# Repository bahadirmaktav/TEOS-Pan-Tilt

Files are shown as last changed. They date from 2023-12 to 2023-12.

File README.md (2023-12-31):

# Teos Pan Tilt
Teos Pan Tilt is a robotic camera project that can pan horizontally and tilt vertically by controlling it via a user interface.</br>
Source codes and design files related to the software, firmware and mechanical design of the project are located in Teos-Pan-Tilt repository.

## Table of Contents
- [Getting Started](#getting-started)
    - [Firmware](#firmware)
    - [Software](#software)
    - [Mechanics](#mechanics)
- [How To Use](#how-to-use)
- [Demo](#demo)
- [Roadmap](#roadmap)
- [License](#license)

## Getting Started
The project basically consists of three folders.</br>
1. The folder named **firmware** contains the source codes running in the camera module used in the project.
2. The folder named **software** contains the source codes of the user interface.
3. The folder named **mechanics** contains files related to the mechanical design of the project.

### Firmware
The **firmware** runs on the ESP32-CAM module. The v5.1 version of the Espressif IoT Development Framework (IDF) was used in the development of the firmware.</br>
Basically, the functions of the firmware are as follows.</br>
1. Connects to the WiFi network specified in the configuration.
2. Starts a WebSocket server.
3. Rotates the pan and tilt cameras according to the commands coming from the user interface via websocket.
4. Sends camera images to the user interface via websocket according to the camera start/stop command coming from the user interface.

### Software
The **software** is a user interface developed with python (tkinter library) that can run in Windows or Linux environments.</br>
Basically, the functions of the software are as follows.</br>
1. Sends command messages to the websocket server according to the input from the user.
2. Displays the visual data coming from the server in video format on the user interface when the camera is started.

### Mechanics
The **mechanics** contain 3D design files in 3mf format developed with Fusion 360.</br>
The mechanical system was designed so that the module with the camera can move in two axes with servo motors.

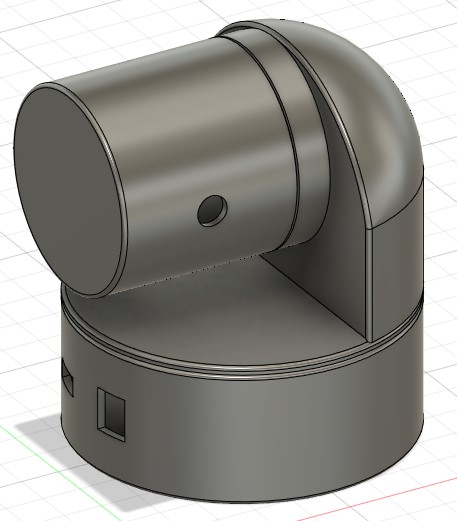
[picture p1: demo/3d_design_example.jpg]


## How To Use
Teos Pan Tilt is controlled from the user interface that appears on the screen by running the source code in the software folder.</br>
An example user interface image for the final version of the project is shared below.</br>

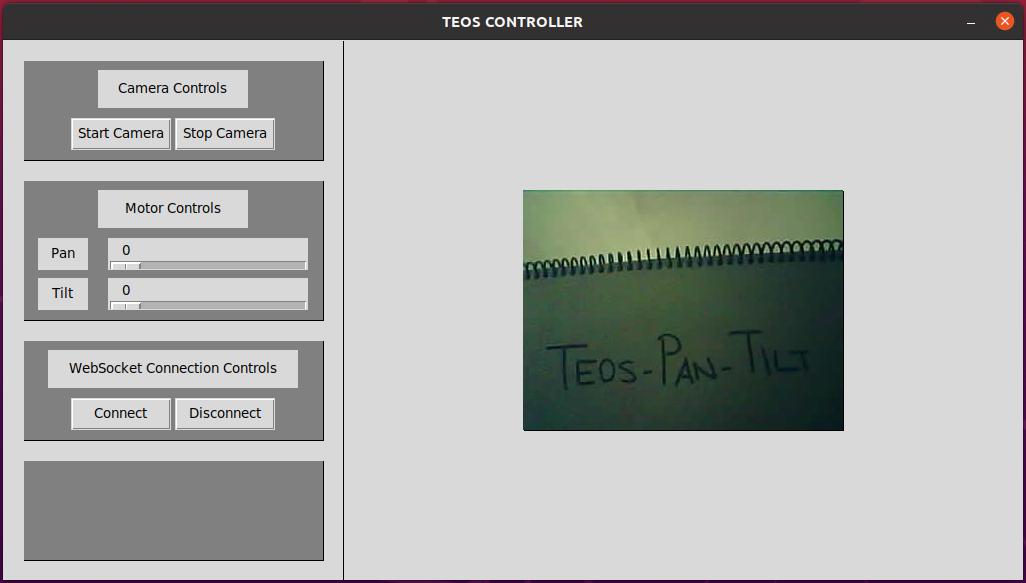
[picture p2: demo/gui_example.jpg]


As you can see on the GUI example image, user can control camera, motor and websocket connection on interface. *In this version, the user can first connect to the websocket server and then control the motors and camera after seeing the log message on the console stating that the connection has been started.*

## Demo
A gif will be added for the demo example.

## Roadmap
- [x] [Firmware]    Setup IDF environment.
- [x] [Firmware]    Develop servo motor controller interface.
- [x] [Firmware]    Develop WiFi and WebSocket server components.
- [x] [Firmware]    Implement esp32-camera library and get image from ESP32-Camera module.
- [x] [Firmware]    Develop command handler interface.
- [x] [Firmware]    Test command handler mechanism (with Postman), camera and motor controls separately.
- [ ] [Firmware]    Fix bug with camera and motors working together.
- [ ] [Firmware]    Make the camera configurable according to the incoming command from client.
- [x] [Software]    Setup python virtual environment.
- [x] [Software]    Develop websocket client interface.
- [x] [Software]    Develop command manager interface.
- [x] [Software]    Develop camera manager.
- [x] [Software]    Develop UI manager which setups window, buttons, display panel.
- [x] [Software]    Integrate command manager with other manager utilities and attach to UI.
- [x] [Software]    Test commands sended from GUI with firmware.
- [ ] [Software]    Integrate an indicator that shows the status of the websocket server. 
- [ ] [Software]    Add face detection algorithm for the images taken from the camera.
- [ ] [Software]    Add algorithm for controlling motors automatically according to the position of detected image.
- [ ] [Software]    Add GUI option for change the system mode between manual and auto.
- [ ] [Software]    Add GUI option for sending camera configurations to server for setting camera parameters such as resolution etc.
- [x] [Mechanics]   Develop basic 3D designs for servo motors and ESP32-Camera module.
- [x] [Mechanics]   Design mechanical parts of pan tilt project and print them with 3D printer.
- [x] [Mechanics]   Assemble the parts.
- [x] [Electronics] Make the necessary pin connections for the motors, power supply and camera module board.

## License
License information will be added.

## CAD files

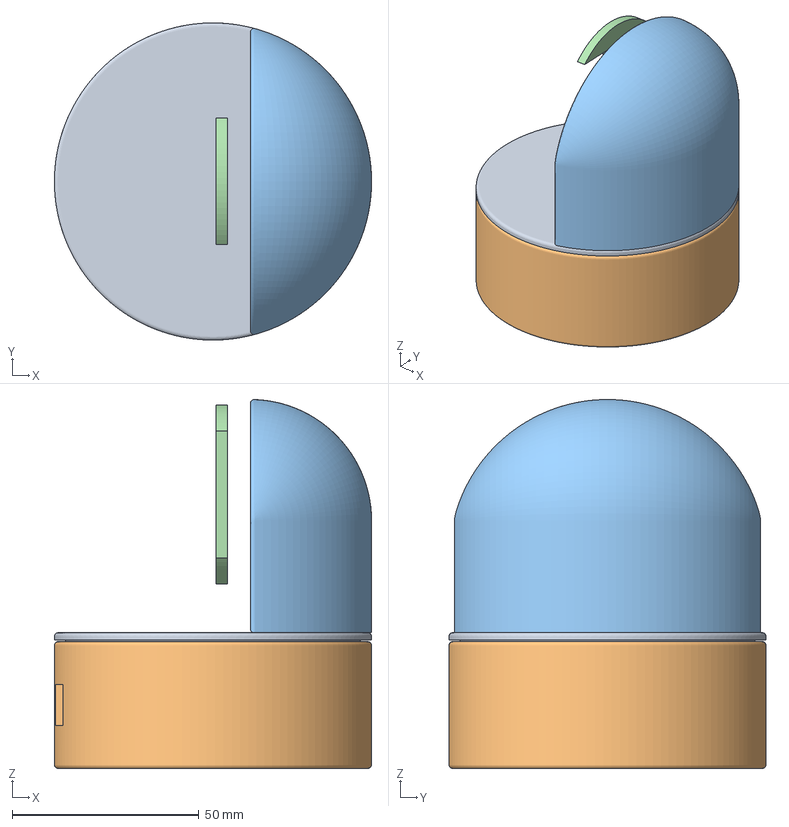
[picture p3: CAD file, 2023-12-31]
mechanics/teos-pan-tilt-box-v21.3mf
85.0 x 85.0 x 98.9 mm
pan-box-cover
pan-motor-box
tilt-motor-box
tilt-motor-holder

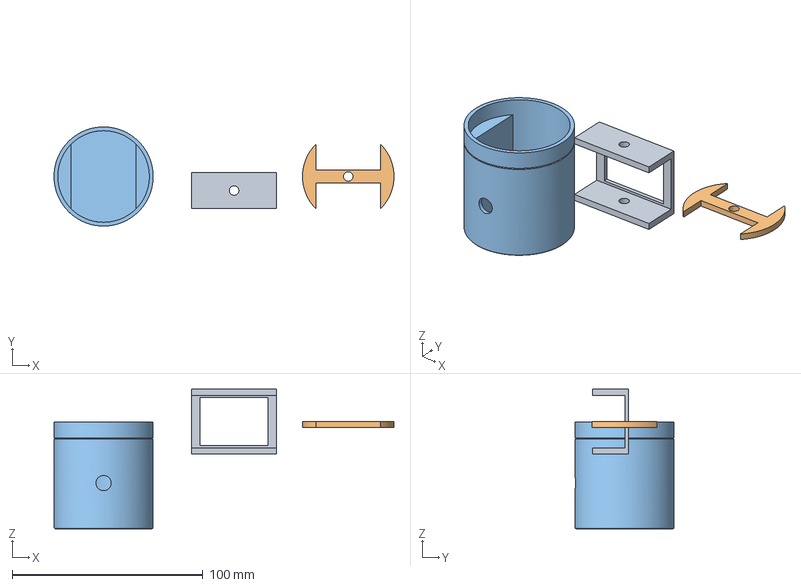
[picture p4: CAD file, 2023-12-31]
mechanics/tilt-unit-updated-parts.3mf
178.2 x 52.0 x 73.3 mm
cam-cylinder

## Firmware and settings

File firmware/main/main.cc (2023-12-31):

#include "freertos/FreeRTOS.h"
#include "freertos/task.h"
#include "esp_log.h"
#include "nvs_flash.h"
#include "esp_heap_caps.h"

#include "WiFi.h"
#include "WebSocketServer.h"
#include "ServoMotorController.h"
#include "CameraController.h"
#include "CommandHandler.h"

static const char *TAG = "APPLICATION";

#ifdef __cplusplus
extern "C" {
#endif

CameraController camera_controller;
ServoMotorController pan_motor_controller(GPIO_NUM_13, LEDC_CHANNEL_0, 0.5, 2.5, 50, LEDC_TIMER_10_BIT, 0, 180);
ServoMotorController tilt_motor_controller(GPIO_NUM_15, LEDC_CHANNEL_1, 0.5, 2.5, 50, LEDC_TIMER_10_BIT, 0, 180);

void app_main(void) {
  // Initialize components
  CommandHandler::Instance().SetCameraController(&camera_controller);
  CommandHandler::Instance().SetServoMotorControllers(&pan_motor_controller, &tilt_motor_controller);
  ESP_LOGI(TAG, "Components initialized.");

  // TODO(MBM) Move NVS into a component.
  // Initialize NVS (Non Volatile Storage)
  esp_err_t ret = nvs_flash_init();
  if (ret == ESP_ERR_NVS_NO_FREE_PAGES || ret == ESP_ERR_NVS_NEW_VERSION_FOUND) {
    ESP_ERROR_CHECK(nvs_flash_erase());
    ret = nvs_flash_init();
  }
  ESP_ERROR_CHECK(ret);
  ESP_LOGI(TAG, "NVS initialized.");

  // Connect to WiFi
  WiFi::Instance().Connect();
  ESP_LOGI(TAG, "WiFi connected.");

  // Start WebSocket Server
  WebSocketServer::Instance().StartServer();
  ESP_LOGI(TAG, "WebSocket server started.");
}
    
#ifdef __cplusplus
}
#endif

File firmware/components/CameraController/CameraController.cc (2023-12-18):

/*
 * CameraController.cc
 *
 *  Created on: Dec 8, 2023
 *      Author: Mehmet Bahadır Maktav
 */

#include "CameraController.h"

#include "freertos/FreeRTOS.h"
#include "freertos/task.h"
#include <esp_log.h>

// Pin configurations - ESP32Cam (AiThinker)
#define CAM_PIN_PWDN 32
#define CAM_PIN_RESET -1 //software reset will be performed
#define CAM_PIN_XCLK 0
#define CAM_PIN_SIOD 26
#define CAM_PIN_SIOC 27

#define CAM_PIN_D7 35
#define CAM_PIN_D6 34
#define CAM_PIN_D5 39
#define CAM_PIN_D4 36
#define CAM_PIN_D3 21
#define CAM_PIN_D2 19
#define CAM_PIN_D1 18
#define CAM_PIN_D0 5
#define CAM_PIN_VSYNC 25
#define CAM_PIN_HREF 23
#define CAM_PIN_PCLK 22

static const char *TAG = "CAMERA";

CameraController::CameraController() {
  camera_config_.pin_pwdn = CAM_PIN_PWDN;
  camera_config_.pin_reset = CAM_PIN_RESET;
  camera_config_.pin_xclk = CAM_PIN_XCLK;
  camera_config_.pin_sccb_sda = CAM_PIN_SIOD;
  camera_config_.pin_sccb_scl = CAM_PIN_SIOC;

  camera_config_.pin_d7 = CAM_PIN_D7;
  camera_config_.pin_d6 = CAM_PIN_D6;
  camera_config_.pin_d5 = CAM_PIN_D5;
  camera_config_.pin_d4 = CAM_PIN_D4;
  camera_config_.pin_d3 = CAM_PIN_D3;
  camera_config_.pin_d2 = CAM_PIN_D2;
  camera_config_.pin_d1 = CAM_PIN_D1;
  camera_config_.pin_d0 = CAM_PIN_D0;
  camera_config_.pin_vsync = CAM_PIN_VSYNC;
  camera_config_.pin_href = CAM_PIN_HREF;
  camera_config_.pin_pclk = CAM_PIN_PCLK;

  //XCLK 20MHz or 10MHz for OV2640 double FPS (Experimental)
  camera_config_.xclk_freq_hz = 20000000;
  camera_config_.ledc_timer = LEDC_TIMER_0;
  camera_config_.ledc_channel = LEDC_CHANNEL_0;

  camera_config_.pixel_format = PIXFORMAT_JPEG; //YUV422,GRAYSCALE,RGB565,JPEG
  camera_config_.frame_size = FRAMESIZE_QVGA;    //QQVGA-UXGA, For ESP32, do not use sizes above QVGA when not JPEG. The performance of the ESP32-S series has improved a lot, but JPEG mode always gives better frame rates.

  camera_config_.jpeg_quality = 12; //0-63, for OV series camera sensors, lower number means higher quality
  camera_config_.fb_count = 1;       //When jpeg mode is used, if fb_count more than one, the driver will work in continuous mode.
  camera_config_.grab_mode = CAMERA_GRAB_WHEN_EMPTY;
  camera_config_.fb_location = CAMERA_FB_IN_PSRAM;
}

void CameraController::StartCamera() {
  // Check camear streaming already started
  if (stream_image_task_handle_ != NULL) {
    ESP_LOGW(TAG, "Camera already started!");  
    return;
  }
  // Library starts the camera in its initialize call (calls cam_start).
  if (esp_camera_init(&camera_config_) != ESP_OK) {
    ESP_LOGE(TAG, "Camera starting failed.");
    return;
  }
  ESP_LOGI(TAG, "Camera successfully started.");
  // Start streaming camera image
  xTaskCreate(&CameraController::StreamImage, "stream_image", 2048, NULL, 5, &stream_image_task_handle_);
  return;
}

void CameraController::StopCamera() {
  // Delete stream image thread before deinitialize camera
  if (stream_image_task_handle_ == NULL) {
    ESP_LOGW(TAG, "Camera already stopped!");
    return;
  }
  vTaskDelete(stream_image_task_handle_);
  stream_image_task_handle_ = NULL;
  // Library stops the camera in its deinitialize call (calls cam_stop).
  if (esp_camera_deinit() != ESP_OK) {
    ESP_LOGE(TAG, "Camera stopping failed.");
    return;
  }
  ESP_LOGI(TAG, "Camera successfully stoped.");
  return;
}

void CameraController::StreamImage(void *pvParameter) {
  while (1) {
    camera_fb_t *frame_buffer_ = esp_camera_fb_get();
    ESP_LOGI(TAG, "Picture taken! Its size was: %zu bytes", frame_buffer_->len);
    WebSocketServer::Instance().AsyncSendFrame(frame_buffer_->buf, frame_buffer_->len);
    esp_camera_fb_return(frame_buffer_);
    vTaskDelay(pdMS_TO_TICKS(100));
  } 
}

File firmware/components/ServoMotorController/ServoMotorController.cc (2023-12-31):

/*
 * ServoMotorController.cc
 *
 *  Created on: Dec 14, 2023
 *      Author: Mehmet Bahadır Maktav
 */

#include "ServoMotorController.h"

#include <math.h>

#include "esp_log.h"

static const char *TAG = "SERVO_MOTOR_CONTROLLER";

ServoMotorController::ServoMotorController(int pwm_gpio_num, ledc_channel_t ledc_channel, float min_width_ms, float max_width_ms, 
                                           uint32_t timer_frequency, ledc_timer_bit_t duty_resolution,
                                           float min_angle, float max_angle)
  : pwm_gpio_num_(pwm_gpio_num)
  , ledc_channel_(ledc_channel)
{
  uint32_t max_width_duty = (pow(2, (int)duty_resolution) - 1) * max_width_ms / (1000 / timer_frequency);
  min_width_duty_ = (pow(2, (int)duty_resolution) - 1) * min_width_ms / (1000 / timer_frequency);
  duty_per_angle_ = (max_width_duty - min_width_duty_) / (max_angle - min_angle);
  ESP_LOGI(TAG, "Calculated max width duty : %lu | min width duty : %lu | duty per angle : %f", max_width_duty, min_width_duty_, duty_per_angle_);
  Configure(pwm_gpio_num, timer_frequency, duty_resolution);
}

ServoMotorController::~ServoMotorController() {
  ledc_stop(LEDC_LOW_SPEED_MODE, ledc_channel_, 0);
}

void ServoMotorController::RotateToAngle(float angle) {
  uint32_t duty = ((angle * duty_per_angle_) + min_width_duty_);
  ESP_LOGI(TAG, "Rotating to %f angle / %lu duty", angle, duty);
  ledc_set_duty(LEDC_LOW_SPEED_MODE, ledc_channel_, duty);
  ledc_update_duty(LEDC_LOW_SPEED_MODE, ledc_channel_);
}

void ServoMotorController::Configure(int pwm_gpio_num, uint32_t timer_frequency, ledc_timer_bit_t duty_resolution) {
  // Set ledc timer configurations
  ledc_timer_config_t ledc_timer;
  ledc_timer.speed_mode       = LEDC_LOW_SPEED_MODE;
  ledc_timer.timer_num        = LEDC_TIMER_0;
  ledc_timer.duty_resolution  = duty_resolution;
  ledc_timer.freq_hz          = timer_frequency;  
  ledc_timer.clk_cfg          = LEDC_AUTO_CLK;
  ledc_timer_config(&ledc_timer);
  // Set ledc channel configurations
  ledc_channel_config_t ledc_channel;
  ledc_channel.speed_mode     = LEDC_LOW_SPEED_MODE;
  ledc_channel.channel        = ledc_channel_;
  ledc_channel.timer_sel      = LEDC_TIMER_0;
  ledc_channel.intr_type      = LEDC_INTR_DISABLE;
  ledc_channel.gpio_num       = pwm_gpio_num;
  ledc_channel.duty           = 0;
  ledc_channel.hpoint         = 0;
  ledc_channel_config(&ledc_channel);  
}

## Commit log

2023-12-17 Fix motor rotate command
2023-12-18 Add camera image to the window and start with a button click
2023-12-18 Fix camera start/stop control for both firmware and software
    [CameraController.cc, CommandHandler.cc]
2023-12-18 Fix servo motor command controls
    [CommandHandler.cc, main.cc]
2023-12-24 Add mechanics design
    [teos-pan-tilt-box-v13.3mf, tilt-unit-updated-parts.3mf]
2023-12-25 Fix servo motor controller
    [ServoMotorController.cc, main.cc]
2023-12-30 Fix command handle mechanism for firmware
    [CommandHandler.cc, EnumCommandResponse.h, main.cc]
2023-12-31 Fix motor slider controller
    [ServoMotorController.cc]
2023-12-31 Update mechanical design
    [teos-pan-tilt-box-v13.3mf, teos-pan-tilt-box-v21.3mf]
